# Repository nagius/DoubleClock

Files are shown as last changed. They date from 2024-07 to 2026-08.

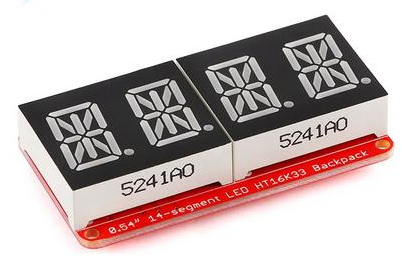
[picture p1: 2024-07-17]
docs/14-segments.png

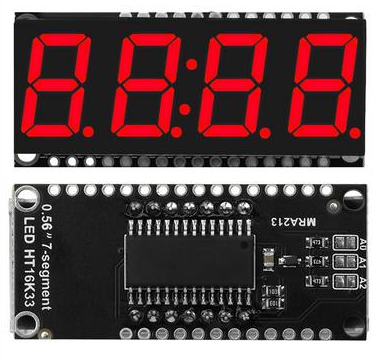
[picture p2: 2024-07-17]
docs/7-segments.png

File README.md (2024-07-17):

# DoubleClock 

## Concept

DoubleClock is a dual timezone alarm clock, with sunrise simulation and music player

Beside displaying two clocks with their respective timezones, this connected alarm clock is meant to provide a soft and natural wake-up at the end of your sleep cycle, like the Philips Wake-up Light but not overpriced.
After a certain delay, a music can be played (like sound of birds or any MP3) to make sure you wake up gradually. 

The choice of red 7 and 14 segments 4-digits display is to give a retro look, 80's style (you can choose any color for your displays, as long as it works with i2c protocol).

This alarm clock can also act as a bedside light if the led strip is powerful enough. It has been designed for 12v or 24v led strip but any voltage should do.

A model for a 3D printed case is available in the `Case/` directory.

## Features

 - Single control button
 - Captive portal on first boot to configure Wifi
 - Sunrise simulation (PWM) for a smooth wake-up.
 - Light sensor for adaptive britghness
 - Configurable numbers of alarms (need recompilation)
 - Support for two music file slots (Chime and Buzzer)
 - Configurable delays for Chime music and Buzzer music when the alarm is on
 - mDNS advertisement at `doubleclock.local`
 - MQTT connection to send events (alarm on, alarm off...)
 - Custom NTP server (to avoid cloud dependencies)
 - JSON API and web page configuration

## Configuration via web interface

A simple web page is available at `http://doubleclock.local/index.html` to configure the alarms.

Javascript required.

## API

A JSON API is available for configuration at `http://doubleclock.local/settings`.
```json
{
  "login": "",                  # Authbasic. Password not displayed.
  "debug": true,
  "serial": true,               # Send logs on serial port
  "ntp": "pool.ntp.org",
  "delays": {
    "chime": 200,               # Seconds after alarm has been triggered
    "buzzer": 500               # Seconds after Chime has been triggered
  },
  "mqtt": {
    "server": "192.168.1.1",    # Disabled if 0.0.0.0
    "port": 1883
  },
  "alarms": [
    {
      "hour": 9,
      "minute": 31,
      "primary": true,          # primary means the alarm time is against the primary timezone.
      "days": [
        true,                   # Monday
        false,                  # Tuesday
        false,                  # ...
        false,
        false,
        false,
        false
      ]
    },
    {
      "hour": 6,
      "minute": 52,
      "primary": false,
      "days": [
        false,
        true,
        false,
        false,
        false,
        false,
        false
      ]
    }
  ]
}

```

To update the configuration, POST the same payload with the new values. All settings are stored into flash memory and are persistent upon reboot and power loss.

## Authentication

DoubleClock support HTTP Auth Basic authentication (but not https). By default, there is no login required. To enable authentication, set the login and password usng the settings API: 

```
curl -X POST http://doubleclock.local/settings -d '{"login": "myuser", "password":"secret"}'
```

## Bill of materials

- ESP-12E (Node MCU board)
- YS-M3 (Mp3 player board)
- 2x 7-segments 4 digits with HT16K33 backback
- 2x 14-segments 4 digits with HT16K33 backback
- 1x Mosfet BS170
- 3x NPN 2N3904
- Photoresistor
- Resistors : 200, 1k, 4.7k, 10k, 22k, 39k
- Speaker
- Push switch
- Led strip
- 5v regulator board (if led strip not in 5v)

See [Schematics](docs/schematics.png) for more details.

## Compilation and upload

Compile this sketch with Arduino IDE and select board `NodeMCU 1.0 (ESP-12E)`.

To upload the static assets to the flash filesystem, you need to install the plugin [arduino-littlefs-upload](https://github.com/earlephilhower/arduino-littlefs-upload). Then hit `ctrl-shift-p` and select `Upload LittleFS to pico/ESP8266/ESP32`. Make sure the serial console is closed before.

## License

Copyleft 2024 - Nicolas AGIUS - GNU GPLv3

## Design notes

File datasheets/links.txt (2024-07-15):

https://www.instructables.com/How-to-use-the-TEA5767-FM-Radio-module-Arduino-Tut/
https://diyusthad.com/2019/07/ys-m3-sound-module.html

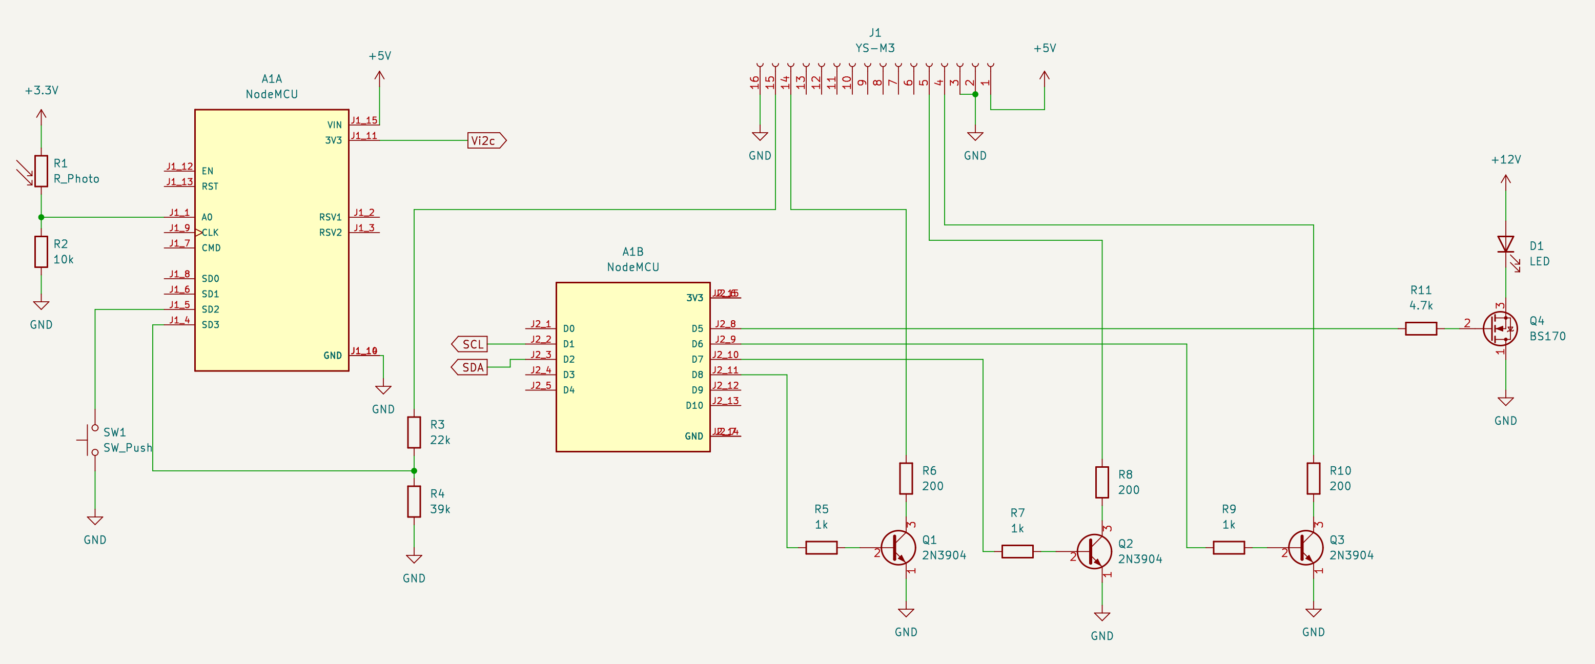
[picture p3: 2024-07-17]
docs/schematics.png

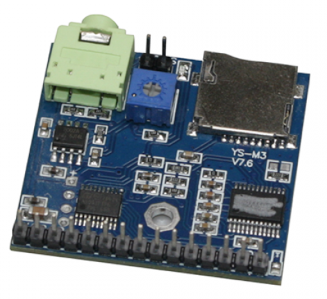
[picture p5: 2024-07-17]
docs/YS-M3.png

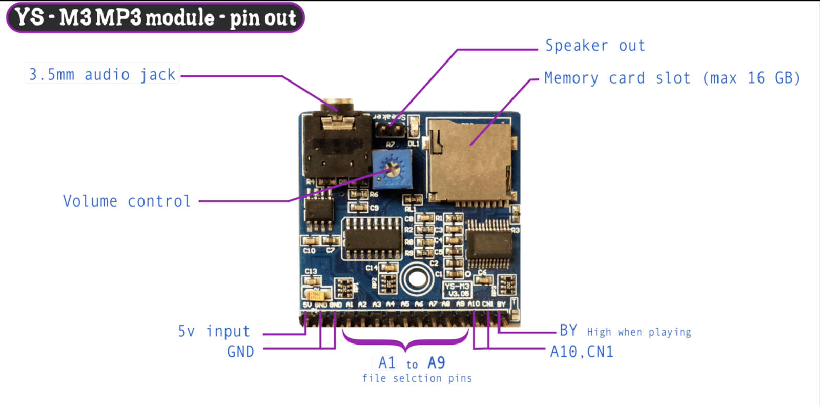
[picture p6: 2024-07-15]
datasheets/YS-M3.jpg

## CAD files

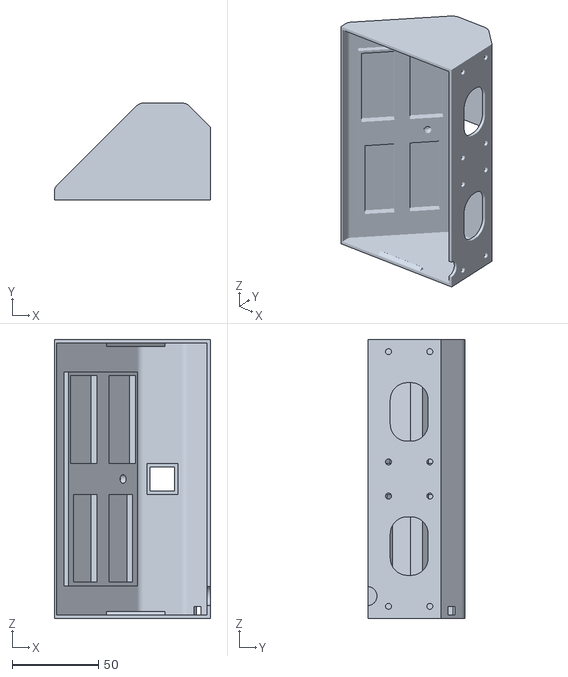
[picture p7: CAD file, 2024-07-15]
Case/case.stl
90.8 x 56.5 x 162.0

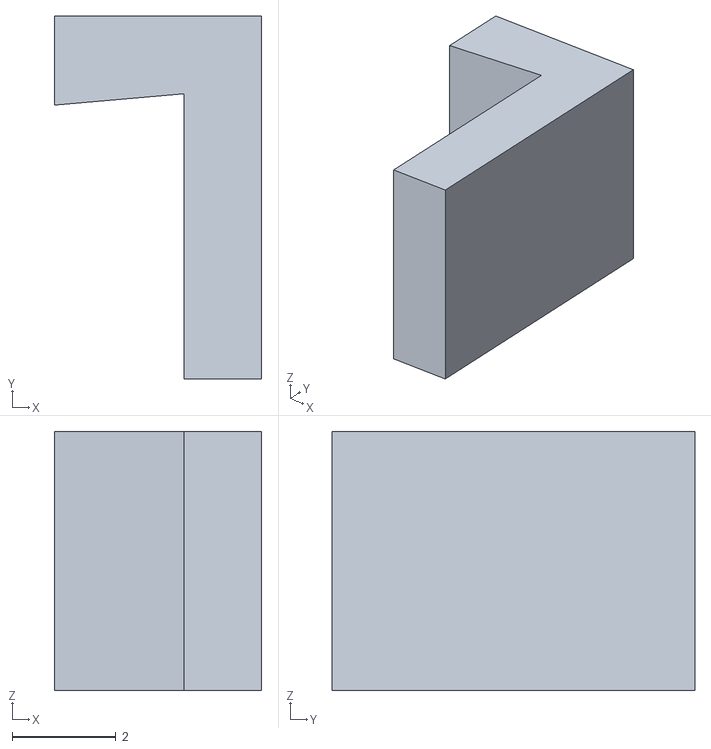
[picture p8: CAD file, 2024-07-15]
Case/hook.stl
4.00 x 7.00 x 5.00

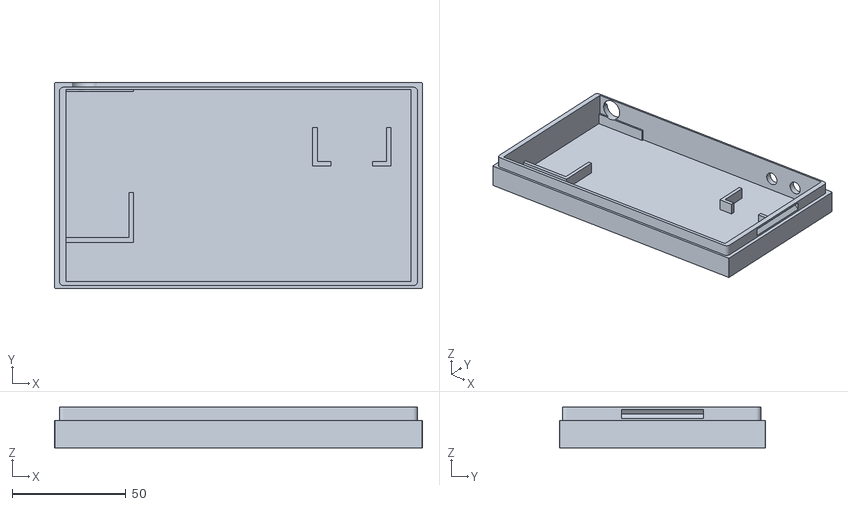
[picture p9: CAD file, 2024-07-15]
Case/base.stl
162.0 x 90.8 x 18.0

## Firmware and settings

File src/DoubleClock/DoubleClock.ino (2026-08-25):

/*************************************************************************
 *
 * This file is part of the DoubleClock Arduino sketch.
 * Copyleft 2024 Nicolas Agius <nicolas.agius@lps-it.fr>
 *
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
 * ***********************************************************************/


#include <ESP8266WiFi.h>         
#include <ESP8266mDNS.h>
#include <ESP8266WebServer.h>
#include <ArduinoJson.h>
#include <PubSubClient.h>
#include <WiFiManager.h>              // See https://github.com/tzapu/WiFiManager for documentation
#include <EEPROM.h>
#include <ezTime.h>
#include "Logger.h"
#include "display.h"
#include <Wire.h>
#include <Adafruit_GFX.h>
#include "Adafruit_LEDBackpack.h"
#include <LittleFS.h>

// Behavior configuration
#define RISING_TIME 200               // seconds to full britghness when alarm triggers
#define ADC_MIN_THRESHOLD 300         // mV from photoresistor in darkness
#define ADC_MAX_THRESHOLD 1000        // mV from photoresistor in sunlight
#define ALARM_COUNT 2                 // Number of alarms
//#define ALLOW_CORS_FOR_LOCAL_DEV

// Default value
#define DEFAULT_HOSTNAME "DoubleClock"
#define DEFAULT_LOGIN ""              // AuthBasic credentials
#define DEFAULT_PASSWORD ""           // (default no auth)
#define DEFAULT_DELAY 0               // Chime and buzzer disabled by default
#define DEFAULT_NTP_SERVER "pool.ntp.org"
#define DEFAULT_MQTT_SERVER "0.0.0.0"
#define DEFAULT_MQTT_PORT 1883
#define DEFAULT_MQTT_TOPIC "doubleclock"
#define DEFAULT_ALARM_TIMEOUT 1800    // 30 minutes
#define DEFAULT_TIMEZONE_A "Europe/London"
#define DEFAULT_TIMEZONE_B "Europe/Madrid"

// Internal constant
#define VERSION "2.1"
#define AUTHBASIC_LEN 21        // Login or password 20 char max
#define BUF_SIZE 512            // Used for string buffers
#define DNS_SIZE 63             // used for DNS names (should be 255 but 63 is enough)
#define PWMRANGE 255            // Max value for pwm ouptut

#define STATE_OFF 1             // Nothing
#define STATE_ON 2              // Light on, no alarm
#define STATE_RING 3            // Alarm trigerred with lights on
#define STATE_RING_CHIME 4      // Alarm trigerred with lights on and music A
#define STATE_RING_BUZZER 5     // Alarm trigerred with lights on and music B

// GPIO configuration
#define I2C_ADDR_TIME_A 0x73    // 7 segments
#define I2C_ADDR_TIME_B 0x72    // 7 segments
#define I2C_ADDR_TEXT_A 0x74    // 13 segments
#define I2C_ADDR_TEXT_B 0x75    // 13 segments
#define GPIO_BUTTON 9           // SD2
#define GPIO_LIGHT 14           // D5
#define GPIO_MUSIC_CHIME 12     // D6
#define GPIO_MUSIC_BUZZER 13    // D7
#define GPIO_MUSIC_OFF 15       // D8
#define GPIO_MUSIC_IN 10        // SD3
#define GPIO_LIGHT_SENSOR A0    // ADC0

struct ST_ALARM {
  uint8_t hour;
  uint8_t minute;
  bool days[7];     // 7 days a week: 0-Monday..6-Sunday
  bool primary;     // Primary is tzA, seconday is tzB
};

struct ST_SETTINGS {
  bool debug;
  bool serial;
  char login[AUTHBASIC_LEN];
  char password[AUTHBASIC_LEN];
  char ntp_server[DNS_SIZE];
  char mqtt_server[DNS_SIZE];
  uint16_t mqtt_port;
  uint16_t alarm_chime_delay;
  uint16_t alarm_buzzer_delay;
  ST_ALARM alarms[ALARM_COUNT];
};

// Global variables
WiFiClient wifiClient;
PubSubClient mqtt(wifiClient);
ESP8266WebServer server(80);
Logger logger = Logger();
ST_SETTINGS settings;
bool shouldSaveConfig = false;    // Flag for WifiManager custom parameters
char buffer[BUF_SIZE];            // Global char* to avoir multiple String concatenation which causes RAM fragmentation
StaticJsonDocument<BUF_SIZE> json_output;

Adafruit_AlphaNum4 alnumA = Adafruit_AlphaNum4();
Adafruit_AlphaNum4 alnumB = Adafruit_AlphaNum4();
Adafruit_7segment timeA = Adafruit_7segment();
Adafruit_7segment timeB = Adafruit_7segment();
Display textA = Display(alnumA);
Display textB = Display(alnumB);
Timezone tzA;
Timezone tzB;

uint8_t state = STATE_OFF;
long alarm_start_time = 0;        // counter for alarm delay
bool previous_button = false;     // Used for debouncing
long last_display_refresh = 0L;   // Timer to refresh displays every seconds
bool dot;                         // Flip-flop for dot display


/**
 * GPIO helpers 
 ********************************************************************************/

void light_off()
{
  analogWrite(GPIO_LIGHT, 0);
}

void light_on(int duty_cycle)
{
  analogWrite(GPIO_LIGHT, duty_cycle);
}

bool isButtonPressed()
{
  // Detect rising edge
  bool pressed = !digitalRead(GPIO_BUTTON);
  if(pressed)
  {
    if(!previous_button)
    {
      logger.info("Button pressed");
      previous_button=true;
      return true;
    }
  }
  else
  {
    previous_button = false;
  }
  
  return false;
}

void music_off()
{
  if(is_music_playing())
  {
    digitalWrite(GPIO_MUSIC_OFF, HIGH);
    delay(250);
    digitalWrite(GPIO_MUSIC_OFF, LOW);
  }
}

void music_buzzer_on()
{
  digitalWrite(GPIO_MUSIC_BUZZER, HIGH);
  delay(250);
  digitalWrite(GPIO_MUSIC_BUZZER, LOW);
}

void music_chime_on()
{
  digitalWrite(GPIO_MUSIC_CHIME, HIGH);
  delay(250);
  digitalWrite(GPIO_MUSIC_CHIME, LOW);
}


bool is_music_playing()
{
  return digitalRead(GPIO_MUSIC_IN) == HIGH;
}

// Return the ideal brightness for the display between 0 (min) and 15 (max)
// based on the photoresistor value
uint8_t get_brightness()
{
  // Sensor in is the dark at 300mV and full light at 1024mV
  // Convert mV to brightness level with affine function y=ax+b
  // Low point (MIN, 0); high point (MAX, 15)
  
  // a = (y2 – y1)/(x2 – x1)
  float a = (15.0 - 0.0) / ( ADC_MAX_THRESHOLD - ADC_MIN_THRESHOLD ) ;

  // b = y1 - ax1
  float b = 0.0 -(a * ADC_MIN_THRESHOLD);
  
  int x = analogRead(A0);
  float y = ((a * x) + b);
  
  if(y<0)
  {
    return 0;
  }
  else if(y>15)
  {
    return 15;
  }
  return (int)y;
}


/**
 * MQTT helpers
 ********************************************************************************/

void setupMQTT()
{
  if(is_mqtt_enabled())
  {
    textA.setMsg("MQTT");
    mqtt.setServer(settings.mqtt_server, settings.mqtt_port);
    logger.info("MQTT enabled at %s:%i", settings.mqtt_server, settings.mqtt_port);
  }
}

bool is_mqtt_enabled()
{
  return strcmp(settings.mqtt_server, "0.0.0.0") != 0;
}

void mqtt_connect()
{
  while (!mqtt.connected())
  {
    logger.info("Connecting to MQTT server...");
    if (mqtt.connect("ESP8266Client"))
    {
      logger.info("MQTT connected.");
    }
    else
    {
      logger.info("MQTT ERROR (%i). Retry in 5s...", mqtt.state());
      delay(5000);
    }
  }
}

void mqtt_loop()
{
  if(is_mqtt_enabled())
  {
    // MQTT reconnection
    if(!mqtt.loop())
    {
      mqtt_connect();
    }
  }
}

void mqtt_publish(char* event)
{
  if(is_mqtt_enabled())
  {
    snprintf(buffer, BUF_SIZE, "{ \"event\": \"%s\" }", event);
    logger.debug("Sending MQTT payload '%s' on topic %s", buffer, DEFAULT_MQTT_TOPIC);
    if(!mqtt.publish(DEFAULT_MQTT_TOPIC, buffer, true))
    {
      logger.info("MQTT publish failed");
    }
  }
}

/**
 * Time helpers 
 ********************************************************************************/


void alarm()
{
  if(state == STATE_ON || state == STATE_OFF)
  {
    logger.info("Alarm trigerred");
    state = STATE_RING;
    alarm_start_time = millis();
    mqtt_publish("alarm-on");
  }
}

void stop_alarm()
{
  if(state >= STATE_RING)
  {
    logger.info("Alarm stopped");
    mqtt_publish("alarm-off");

    music_off();

    action_light_on(); // Keep light on after alarm is disabled
  }
}

void ring()
{
  long alarm_duration = (millis() - alarm_start_time);

  // Switch on PWM light
  int duty_cycle = alarm_duration * PWMRANGE / (RISING_TIME * 1000);
 
  if(duty_cycle > PWMRANGE)
    duty_cycle=PWMRANGE;

  light_on(duty_cycle);

  // Switch on music
  if(state == STATE_RING_CHIME)
  {
    if(!is_music_playing() && settings.alarm_chime_delay!=0)
      music_chime_on();
  }

  if(state == STATE_RING_BUZZER)
  {
    if(!is_music_playing() && settings.alarm_buzzer_delay!=0)
      music_buzzer_on();
  }
}

void refresh_displays()
{
    if(state >= STATE_RING) {
      textA.setMsg("WAKE UP   ");
      textB.setMsg(" today is " + dayStr(tzA.weekday()) + "  ");
    } else {
      textA.setMsg(tzA.dateTime("T"));
      textB.setMsg(tzB.dateTime("T"));
    }
    textA.tick();
    textB.tick();

    dot=!dot;
  
    timeA.print(tzA.hour()*100 + tzA.minute());
    timeA.drawColon(dot);
    timeA.writeDisplay();

    timeB.print(tzB.hour()*100 + tzB.minute());
    timeB.drawColon(dot);
    timeB.writeDisplay();
}


void setupDisplays()
{
  alnumA.begin(I2C_ADDR_TEXT_A);
  alnumA.clear();
  alnumA.writeDisplay();
  textA = Display(alnumA);

  alnumB.begin(I2C_ADDR_TEXT_B);
  alnumB.clear();
  alnumB.writeDisplay();
  textB = Display(alnumB);

  timeA.begin(I2C_ADDR_TIME_A);
  timeA.clear();
  timeA.writeDisplay();

  timeB.begin(I2C_ADDR_TIME_B);
  timeB.clear();
  timeB.writeDisplay();

  setBrightness();
}

void setBrightness()
{
  uint8_t b = get_brightness();
  alnumA.setBrightness(b);
  alnumB.setBrightness(b);    
  timeA.setBrightness(b);
  timeB.setBrightness(b);    
}

void setupNTP()
{
  textA.setMsg("NTP");
  tzA.setLocation(DEFAULT_TIMEZONE_A);
  tzB.setLocation(DEFAULT_TIMEZONE_B);
  setDebug(INFO);   // ezTime debug
  setServer(settings.ntp_server);
  waitForSync(60);  // 60s timeout on initial NTP request
}

void setupMDNS()
{
  textA.setMsg("mDNS");
  if(MDNS.begin(DEFAULT_HOSTNAME))
  {
    MDNS.addService("http", "tcp", 80);
    logger.info("mDNS activated.");
  }
  else
  {
    logger.info("Error setting up mDNS responder");
  }
  delay(500);
}

void setup()
{
  WiFiManager wifiManager;
  
  Serial.begin(115200);
  EEPROM.begin(512);
  if(!LittleFS.begin())
  {
    logger.info("ERROR: LittleFS failed");
    return;
  }

  logger.info("DoubleClock version %s started.", VERSION);

  // Setup GPIO
  pinMode(GPIO_MUSIC_CHIME, OUTPUT);
  digitalWrite(GPIO_MUSIC_CHIME, LOW);
  pinMode(GPIO_MUSIC_BUZZER, OUTPUT);
  digitalWrite(GPIO_MUSIC_BUZZER, LOW);
  pinMode(GPIO_MUSIC_OFF, OUTPUT);
  music_off();
  pinMode(GPIO_MUSIC_IN, INPUT);
  pinMode(GPIO_BUTTON, INPUT_PULLUP);
  pinMode(GPIO_LIGHT, OUTPUT);
  light_off();
  setupDisplays();

  // Load settigns from flash
  loadSettings();
  
  // Configure custom parameters
  WiFiManagerParameter http_login("htlogin", "HTTP Login", settings.login, AUTHBASIC_LEN);
  WiFiManagerParameter http_password("htpassword", "HTTP Password", settings.password, AUTHBASIC_LEN, "type='password'");
  wifiManager.setSaveConfigCallback([](){
    shouldSaveConfig = true;
  });
  wifiManager.addParameter(&http_login);
  wifiManager.addParameter(&http_password);
  
  // Connect to Wifi or ask for SSID
  textA.setMsg("WIFI");
  wifiManager.setHostname(DEFAULT_HOSTNAME);
  wifiManager.autoConnect(DEFAULT_HOSTNAME);

  // Save new configuration set by captive portal
  if(shouldSaveConfig)
  {
    strncpy(settings.login, http_login.getValue(), AUTHBASIC_LEN);
    strncpy(settings.password, http_password.getValue(), AUTHBASIC_LEN);

    logger.info("Saving new config from portal web page");
    saveSettings();
  }

  // Display local ip
  logger.info("Connected. IP address: %s", WiFi.localIP().toString().c_str());

  // Setup HTTP handlers
#ifdef ALLOW_CORS_FOR_LOCAL_DEV
  server.enableCORS(true);
  server.on("/settings", HTTP_OPTIONS, []() {
    server.sendHeader("Access-Control-Allow-Headers", "*");
    server.sendHeader("Access-Control-Allow-Methods", "POST,GET,OPTIONS");
    server.send(204);
 });
#endif
  server.on("/", handleGETRoot );
  server.on("/debug", HTTP_GET, handleGETDebug);
  server.on("/settings", HTTP_GET, handleGETSettings);
  server.on("/settings", HTTP_POST, handlePOSTSettings);
  server.on("/action", HTTP_POST, handlePOSTAction);
  server.on("/reset", HTTP_POST, handlePOSTReset);
  server.onNotFound([]() {
    // Serve arbitrary requested file from LittleFS if exist
    if (!handleFileRead(server.uri()))
      server.send(404, "text/plain", "Not found\r\n");
  });
  server.begin();
  
  logger.info("HTTP server started.");

  setupNTP();
  setupMQTT();
  setupMDNS();
}

void action_light_on()
{
  light_on(255);
  mqtt_publish("light-on");
  state = STATE_ON;
}

void action_light_off()
{
  light_off();
  mqtt_publish("light-off");
  state = STATE_OFF;
}

void action_alarm_off()
{
  stop_alarm();
}

void loop()
{
  MDNS.update();
  server.handleClient();
  events();  // EZTime events
  mqtt_loop();

  if(isButtonPressed())
  {
    switch (state) {
      case STATE_OFF:
        action_light_on();
        break;

      case STATE_ON:
        action_light_off();
        break;

      default:
        action_alarm_off();
        break;
    }
  } 
  else if(state >= STATE_RING)
  {
    long alarm_duration_ms = (millis() - alarm_start_time);
    
    if(state == STATE_RING && settings.alarm_chime_delay != 0 && alarm_duration_ms >= settings.alarm_chime_delay*1000)
    {
      logger.debug("ALARM chime on");
      state = STATE_RING_CHIME;
      mqtt_publish("alarm-chime");
    }

    if(state == STATE_RING_CHIME && settings.alarm_buzzer_delay != 0 && alarm_duration_ms >= (settings.alarm_chime_delay+settings.alarm_buzzer_delay)*1000)
    {
      logger.debug("ALARM buzzer on");
      state = STATE_RING_BUZZER;
      music_off();
      mqtt_publish("alarm-buzzer");
    }

    if(alarm_duration_ms >= DEFAULT_ALARM_TIMEOUT*1000)
    {
      stop_alarm();
      action_light_off();
      mqtt_publish("alarm-cancelled");
    }

    ring();
  }
  else
  {
    // Trigger alarm
    if(tzA.second() == 0) // Only trigger alarm during one second per minute
    {
      for(int i; i<ALARM_COUNT; i++)
      {
        tmElements_t tm;
        if(settings.alarms[i].primary)
        {
          // use breakTime to get day, hour and minute in an atomic way
          breakTime(tzA.now(), tm);
        }
        else
        {
          breakTime(tzB.now(), tm);
        }

        // today is Monday = 0 Sunday = 7; tm.Wday is Sunday = 1
        int today = (tm.Wday + 5) % 7;
        if(settings.alarms[i].days[today] && settings.alarms[i].hour == tm.Hour && settings.alarms[i].minute == tm.Minute)
        {
          alarm();
          break;
        }
      }
    }
  }

  long current_millis = millis();
  if(current_millis - last_display_refresh > 1000)
  {
    setBrightness();
    refresh_displays();
    
    // update the timing variable
    last_display_refresh = current_millis;
  }
}

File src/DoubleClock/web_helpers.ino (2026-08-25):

/*
 * This file is part of DoubleClock Arduino sketch under GPLv3
 * All HTTP/Web handlers for ESP8266WebServer are here  for ease of navigation.
 *
 * Global variables are defined in the main ino file.
 */

/**
 * HTTP route handlers
 ********************************************************************************/

/**
 * GET /
 */
void handleGETRoot() 
{
  // I always loved this HTTP code
  server.send(418, F("text/plain"), F("\
            _           \r\n\
         _,(_)._            \r\n\
    ___,(_______).          \r\n\
  ,'__.           \\    /\\_  \r\n\
 /,' /             \\  /  /  \r\n\
| | |              |,'  /   \r\n\
 \\`.|                  /    \r\n\
  `. :           :    /     \r\n\
    `.            :.,'      \r\n\
      `-.________,-'        \r\n\
  \r\n"));
}


/**
 * GET /debug
 */
void handleGETDebug()
{
  if(!isAuthBasicOK())
    return;
 
  server.send(200, F("text/plain"), logger.getLog());
}


/**
 * GET /settings
 */
void handleGETSettings()
{
  if(!isAuthBasicOK())
    return;
 
  sendJSONSettings();
}

/**
 * POST /settings
 * Args :
 *   - debug = <bool>
 *   - login = <str>
 *   - password = <str>
 */
void handlePOSTSettings()
{
  StaticJsonDocument<BUF_SIZE> json;

  if(!isAuthBasicOK())
    return;

  DeserializationError error = deserializeJson(json, server.arg("plain"));
  if(error)
  {
    sendJSONError("deserialize failed: %s", error.c_str());
    return;
  }

  if(json.containsKey("debug"))
  {
    settings.debug = json["debug"];
    logger.setDebug(settings.debug);
    logger.info("Updated debug to %s.", settings.debug ? "true" : "false");
  }

  if(json.containsKey("serial"))
  {
    settings.serial = json["serial"];
    logger.setSerial(settings.serial);
    logger.info("Updated serial to %s.", settings.serial ? "true" : "false");
  }

  if(json.containsKey("ntp"))
  {
    const char* ntp_server = json["ntp"];
    strncpy(settings.ntp_server, ntp_server, DNS_SIZE);
    setServer(settings.ntp_server);
    logger.info("Updated NTP server to \"%s\".", settings.ntp_server);
  }

  if(json.containsKey("login"))
  {
    const char* login = json["login"];
    strncpy(settings.login, login, AUTHBASIC_LEN);
    logger.info("Updated login to \"%s\".", settings.login);
  }

  if(json.containsKey("password"))
  {
    const char* password = json["password"];
    strncpy(settings.password, password, AUTHBASIC_LEN);
    logger.info("Updated password.");
  }

  if(json.containsKey("delays"))
  {
    JsonObject delays = json["delays"];
    if(delays.containsKey("chime"))
    {
      const uint16_t seconds = delays["chime"];
      if(seconds>= 0)
      {
        settings.alarm_chime_delay = seconds;
        logger.info("Updated chime delay to %i.", seconds);
      }
      else
      {
        sendJSONError("Invalid chime delay");
        return;
      }
    }

    if(delays.containsKey("buzzer"))
    {
      const uint16_t seconds = delays["buzzer"];
      if(seconds>= 0)
      {
        settings.alarm_buzzer_delay = seconds;
        logger.info("Updated buzzer delay to %i.", seconds);
      }
      else
      {
        sendJSONError("Invalid buzzer delay");
        return;
      }
    }
  }
  
  if(json.containsKey("mqtt"))
  {
    JsonObject mqtt = json["mqtt"];
    if(mqtt.containsKey("server"))
    {
      const char* server = mqtt["server"];
      strncpy(settings.mqtt_server, server, AUTHBASIC_LEN);
    }

    if(mqtt.containsKey("port"))
    {
      const uint16_t port = mqtt["port"];
      settings.mqtt_port = port;
    }

    setupMQTT();
  }

  if(json.containsKey("alarms"))
  {
    JsonArray alarms = json["alarms"];
    if(alarms.size()>ALARM_COUNT)
    {
      sendJSONError("Invalid number of alarms");
      return;
    }

    for(int i=0; i<alarms.size(); i++)
    {
      if(alarms[i].containsKey("hour"))
      {
        const int hour = alarms[i]["hour"];
        if(hour>= 0 && hour <=23)
        {
          settings.alarms[i].hour = hour;
          logger.info("Updated alarm #%d hour to %d.", i, hour);
        }
        else
        {
          sendJSONError("Invalid hour for alarm #%d", i);
          return;
        }
      }

      if(alarms[i].containsKey("minute"))
      {
        const int minute = alarms[i]["minute"];
        if(minute>= 0 && minute <=59)
        {
          settings.alarms[i].minute = minute;
          logger.info("Updated alarm #%d minute to %d.", i, minute);
        }
        else
        {
          sendJSONError("Invalid minute for alarm #%d", i);
          return;
        }
      }

      if(alarms[i].containsKey("primary"))
      {
        settings.alarms[i].primary = alarms[i]["primary"];
      }

      if(alarms[i].containsKey("days"))
      {
        JsonArray days = alarms[i]["days"];
        if(days.size() != 7)
        {
          sendJSONError("Invalid number of days for alarm #%d", i);
          return;
        }

        for(int j=0; j<7; j++)
        {
          const bool day = days[j];
          settings.alarms[i].days[j] = day;
        }
        logger.info("Updated alarm #%d days", i);
      }
    }
  }

  saveSettings();

  // Reply with current settings
  sendJSONSettings();
}

/**
 * POST /reset
 */
void handlePOSTReset()
{
  WiFiManager wifiManager;
  
  if(!isAuthBasicOK())
    return;

  logger.info("Reset settings to default");
    
  //reset saved settings
  wifiManager.resetSettings();
  setDefaultSettings();
  saveSettings();

  // Send response now
  server.send(200, F("text/plain"), F("Reset OK"));
  
  delay(3000);
  logger.info("Restarting...");
    
  ESP.restart();
}

/**
 * POST /action
 * Args :
 *   - action = <str>
 */
void handlePOSTAction()
{
  StaticJsonDocument<BUF_SIZE> json;

  if(!isAuthBasicOK())
    return;

  DeserializationError error = deserializeJson(json, server.arg("plain"));
  if(error)
  {
    sendJSONError("deserialize failed: %s", error.c_str());
    return;
  }

  if(json.containsKey("action"))
  {
    const char* action = json["action"];
    logger.debug("Received action %s.", action);

    if(strcmp(action, "light-on") == 0)
    {
      action_light_on();
    }
    else if(strcmp(action, "light-off") == 0)
    {
      action_light_off();
    }
    else if(strcmp(action, "alarm-off") == 0)
    {
      action_alarm_off();
    }
    else
    {
      sendJSONError("Unknow action: %s", action);
      return;
    }

    json_output.clear();
    json_output["action"] = action;

    serializeJson(json_output, buffer);
    server.send(200, "application/json", buffer);
  }

  sendJSONError("Invalid request, missing action");
}
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

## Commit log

2024-04-20 Tuned case thikness
2024-05-27 Updated case
2024-07-07 Switch settings API to JSON
2024-07-12 Reinforced case
2024-07-15 Added STL files
    [base.stl, case.stl, hook.stl]
2024-07-17 Added Kicad schematics
    [doubleClock.kicad_sch]

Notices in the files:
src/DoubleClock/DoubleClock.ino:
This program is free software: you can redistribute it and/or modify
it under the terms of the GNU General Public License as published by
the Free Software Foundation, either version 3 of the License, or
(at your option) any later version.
